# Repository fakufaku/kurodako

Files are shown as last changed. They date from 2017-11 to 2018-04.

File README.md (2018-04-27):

View this project on [CADLAB.io](https://cadlab.io/node/948). 

Kurodako
========

An eight-channel compact microphone array based on the Beaglebone Black and PDM microphones.

Bill of Materials
-----------------

* 8x SPM1437HM4H-B PDM MEMS Microphones (Mouser 721-SPM1437HM4H-B)
* 8x 100nF capacitors, 0805 package
* 2x pin headers 2x40, 2.54mm spaced

Possibly also:
* 4x 100 ohms resistors

If we want to use wires rather than only PCB microphones:
* 8x Micromatch Male-On-Wire 4 pin connector
* 8x Micromatch Female-One-Board 4 pin connector SMD
* flat cable, 1.27mm, 4 wires

Dependencies
------------

* The PRU code doing the low pass filtering [repo](https://github.com/Scrashdown/PRU-Audio-Processing) [Work in progress]

License
-------

2017 (c) Robin Scheibler

This board was designed by Robin Scheibler and is shared under the [Creative Commons CC-BY-SA](https://creativecommons.org/licenses/by-sa/4.0/) license.

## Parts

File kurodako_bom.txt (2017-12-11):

Partlist exported from /Users/scheibler/Documents/eagle/Kurodako/kurodako.sch at 11.12.17 23:04

Part  Value                    Device                   Package                 Description                                        
C1    0.1uF                    CAP0805                  0805                    Capacitor                                          
C2    0.1uF                    CAP0805                  0805                    Capacitor                                          
C3    0.1uF                    CAP0805                  0805                    Capacitor                                          
C4    0.1uF                    CAP0805                  0805                    Capacitor                                          
C5    0.1uF                    CAP0805                  0805                    Capacitor                                          
C6    0.1uF                    CAP0805                  0805                    Capacitor                                          
C7    0.1uF                    CAP0805                  0805                    Capacitor                                          
C8    0.1uF                    CAP0805                  0805                    Capacitor                                          
J1    CONN-4P-MICROMATCH-SMD   CONN-4P-MICROMATCH-SMD   MICROMATCH-4P-SMD                                                          
J2    CONN-4P-MICROMATCH-SMD   CONN-4P-MICROMATCH-SMD   MICROMATCH-4P-SMD                                                          
J3    CONN-4P-MICROMATCH-SMD   CONN-4P-MICROMATCH-SMD   MICROMATCH-4P-SMD                                                          
J4    CONN-4P-MICROMATCH-SMD   CONN-4P-MICROMATCH-SMD   MICROMATCH-4P-SMD                                                          
J5    CONN-4P-MICROMATCH-SMD   CONN-4P-MICROMATCH-SMD   MICROMATCH-4P-SMD                                                          
J6    CONN-4P-MICROMATCH-SMD   CONN-4P-MICROMATCH-SMD   MICROMATCH-4P-SMD                                                          
J7    CONN-4P-MICROMATCH-SMD   CONN-4P-MICROMATCH-SMD   MICROMATCH-4P-SMD                                                          
J8    CONN-4P-MICROMATCH-SMD   CONN-4P-MICROMATCH-SMD   MICROMATCH-4P-SMD                                                          
J9    CONN-4P-MICROMATCH-SMD   CONN-4P-MICROMATCH-SMD   MICROMATCH-4P-SMD                                                          
J10   CONN-4P-MICROMATCH-SMD   CONN-4P-MICROMATCH-SMD   MICROMATCH-4P-SMD                                                          
J11   CONN-4P-MICROMATCH-SMD   CONN-4P-MICROMATCH-SMD   MICROMATCH-4P-SMD                                                          
J12   CONN-4P-MICROMATCH-SMD   CONN-4P-MICROMATCH-SMD   MICROMATCH-4P-SMD                                                          
J13   CONN-4P-MICROMATCH-SMD   CONN-4P-MICROMATCH-SMD   MICROMATCH-4P-SMD                                                          
J14   CONN-4P-MICROMATCH-SMD   CONN-4P-MICROMATCH-SMD   MICROMATCH-4P-SMD                                                          
J15   CONN-4P-MICROMATCH-SMD   CONN-4P-MICROMATCH-SMD   MICROMATCH-4P-SMD                                                          
J16   CONN-4P-MICROMATCH-SMD   CONN-4P-MICROMATCH-SMD   MICROMATCH-4P-SMD                                                          
MIC1L SPM1437HM4H-B            SPM1437HM4H-B            MEMS-MIC-6PAD                                                              
MIC1R SPM1437HM4H-B            SPM1437HM4H-B            MEMS-MIC-6PAD                                                              
MIC2L SPM1437HM4H-B            SPM1437HM4H-B            MEMS-MIC-6PAD                                                              
MIC2R SPM1437HM4H-B            SPM1437HM4H-B            MEMS-MIC-6PAD                                                              
MIC3L SPM1437HM4H-B            SPM1437HM4H-B            MEMS-MIC-6PAD                                                              
MIC3R SPM1437HM4H-B            SPM1437HM4H-B            MEMS-MIC-6PAD                                                              
MIC4L SPM1437HM4H-B            SPM1437HM4H-B            MEMS-MIC-6PAD                                                              
MIC4R SPM1437HM4H-B            SPM1437HM4H-B            MEMS-MIC-6PAD                                                              
R1    DNI                      R-US_R0805               R0805                   RESISTOR, American symbol                          
R2    DNI                      R-US_R0805               R0805                   RESISTOR, American symbol                          
R3    DNI                      R-US_R0805               R0805                   RESISTOR, American symbol                          
R4    DNI                      R-US_R0805               R0805                   RESISTOR, American symbol                          
R5    DNI                      R-US_R0805               R0805                   RESISTOR, American symbol                          
R6    DNI                      R-US_R0805               R0805                   RESISTOR, American symbol                          
R7    DNI                      R-US_R0805               R0805                   RESISTOR, American symbol                          
R8    DNI                      R-US_R0805               R0805                   RESISTOR, American symbol                          
R9    DNI                      R-US_R0805               R0805                   RESISTOR, American symbol                          
R10   100                      R-US_R0805               R0805                   RESISTOR, American symbol                          
R11   100                      R-US_R0805               R0805                   RESISTOR, American symbol                          
R12   100                      R-US_R0805               R0805                   RESISTOR, American symbol                          
R13   100                      R-US_R0805               R0805                   RESISTOR, American symbol                          
P8    2x23 pin header                                                           pin header 100 mil spacing
P9    2x23 pin header                                                           pin header 100 mil spacing

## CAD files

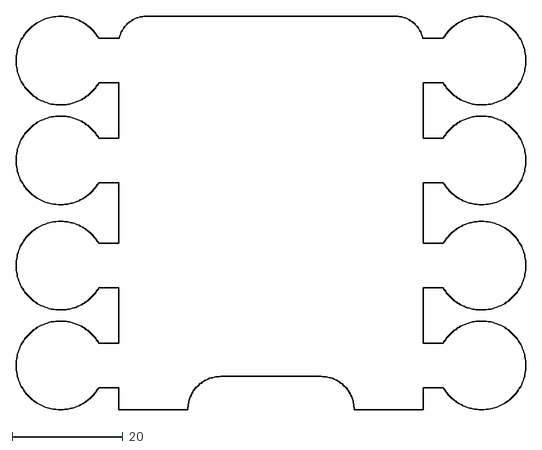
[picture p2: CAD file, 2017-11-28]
pcb_outline/eight_mics_outline.dxf
92.0 x 71.0

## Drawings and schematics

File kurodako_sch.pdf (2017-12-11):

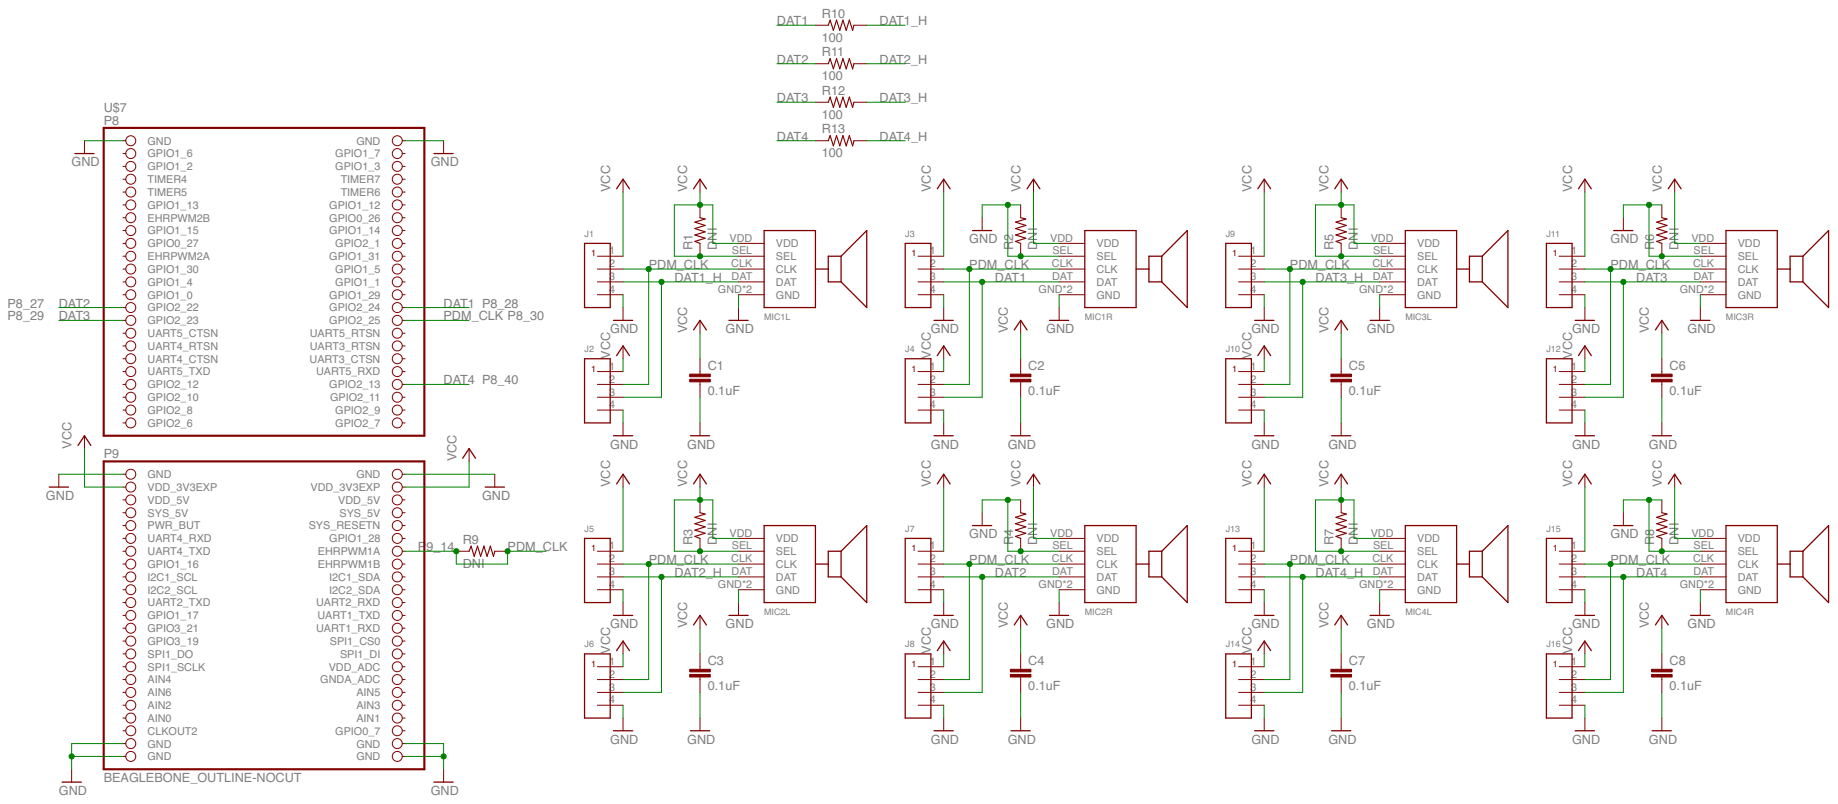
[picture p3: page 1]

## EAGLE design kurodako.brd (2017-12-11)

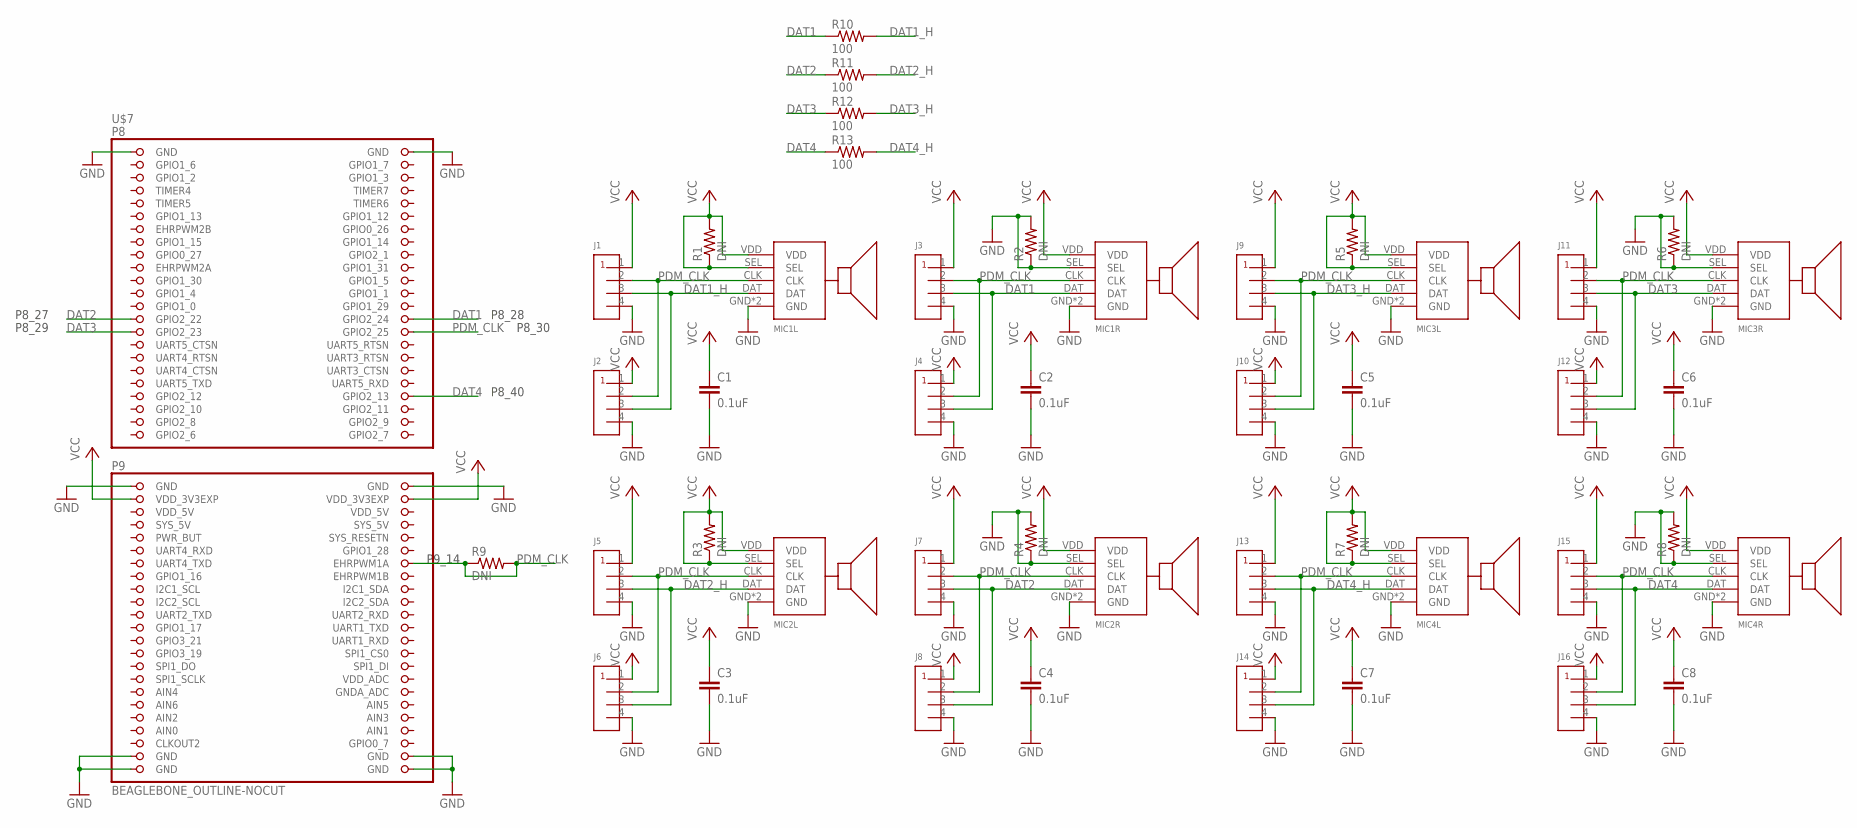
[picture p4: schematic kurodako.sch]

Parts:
C1, C2, C3, C4, C5, C6, C7, C8: 0.1uF; 0805
J1, J2, J3, J4, J5, J6, J7, J8, J9, J10, J11, J12, J13, J14, J15, J16: CONN-4P-MICROMATCH-SMD; MICROMATCH-4P-SMD
MIC1L, MIC1R, MIC2L, MIC2R, MIC3L, MIC3R, MIC4L, MIC4R: SPM1437HM4H-B; MEMS-MIC-6PAD
R1, R2, R3, R4, R5, R6, R7, R8, R9: DNI; R0805
R10, R11, R12, R13: 100; R0805
U$7: BEAGLEBONE_OUTLINE-NOCUT; BEAGLEBONE_SHIELD_NOCUT

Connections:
AIN0: U$7.85 (AIN0)
DAT1: J3.3, J4.3, MIC1R.DAT, R10.1, U$7.28 (GPIO2_24)
DAT1_H: J1.3, J2.3, MIC1L.DAT, R10.2
DAT2: J7.3, J8.3, MIC2R.DAT, R11.1, U$7.27 (GPIO2_22)
DAT2_H: J5.3, J6.3, MIC2L.DAT, R11.2
DAT3: J11.3, J12.3, MIC3R.DAT, R12.1, U$7.29 (GPIO2_23)
DAT3_H: J9.3, J10.3, MIC3L.DAT, R12.2
DAT4: J15.3, J16.3, MIC4R.DAT, R13.1, U$7.40 (GPIO2_13)
DAT4_H: J13.3, J14.3, MIC4L.DAT, R13.2
GND: C1.2, C2.2, C3.2, C4.2, C5.2, C6.2, C7.2, C8.2, J1.4, J2.4, J3.4, J4.4, J5.4, J6.4, J7.4, J8.4, J9.4, J10.4, J11.4, J12.4, J13.4, J14.4, J15.4, J16.4, MIC1L.GND, MIC1L.GND@1 (GND), MIC1R.GND, MIC1R.GND@1 (GND), MIC1R.SEL, MIC2L.GND, MIC2L.GND@1 (GND), MIC2R.GND, MIC2R.GND@1 (GND), MIC2R.SEL, MIC3L.GND, MIC3L.GND@1 (GND), MIC3R.GND, MIC3R.GND@1 (GND), MIC3R.SEL, MIC4L.GND, MIC4L.GND@1 (GND), MIC4R.GND, MIC4R.GND@1 (GND), MIC4R.SEL, R2.1, R2.2, R4.1, R4.2, R6.1, R6.2, R8.1, R8.2, U$7.1 (GND), U$7.2 (GND), U$7.47 (GND), U$7.48 (GND), U$7.89 (GND), U$7.90 (GND), U$7.91 (GND), U$7.92 (GND)
PDM_CLK: J1.2, J2.2, J3.2, J4.2, J5.2, J6.2, J7.2, J8.2, J9.2, J10.2, J11.2, J12.2, J13.2, J14.2, J15.2, J16.2, MIC1L.CLK, MIC1R.CLK, MIC2L.CLK, MIC2R.CLK, MIC3L.CLK, MIC3R.CLK, MIC4L.CLK, MIC4R.CLK, R9.1, R9.2, U$7.30 (GPIO2_25), U$7.60 (EHRPWM1A)
SYS_5V: U$7.53 (SYS_5V)
VCC: C1.1, C2.1, C3.1, C4.1, C5.1, C6.1, C7.1, C8.1, J1.1, J2.1, J3.1, J4.1, J5.1, J6.1, J7.1, J8.1, J9.1, J10.1, J11.1, J12.1, J13.1, J14.1, J15.1, J16.1, MIC1L.SEL, MIC1L.VDD, MIC1R.VDD, MIC2L.SEL, MIC2L.VDD, MIC2R.VDD, MIC3L.SEL, MIC3L.VDD, MIC3R.VDD, MIC4L.SEL, MIC4L.VDD, MIC4R.VDD, R1.1, R1.2, R3.1, R3.2, R5.1, R5.2, R7.1, R7.2, U$7.49 (VDD_3V3EXP), U$7.50 (VDD_3V3EXP)
VDD_5V: U$7.51 (VDD_5V), U$7.52 (VDD_5V)

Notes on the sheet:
P8_40
P8_27
P8_28
P8_29
P8_30
P9_14

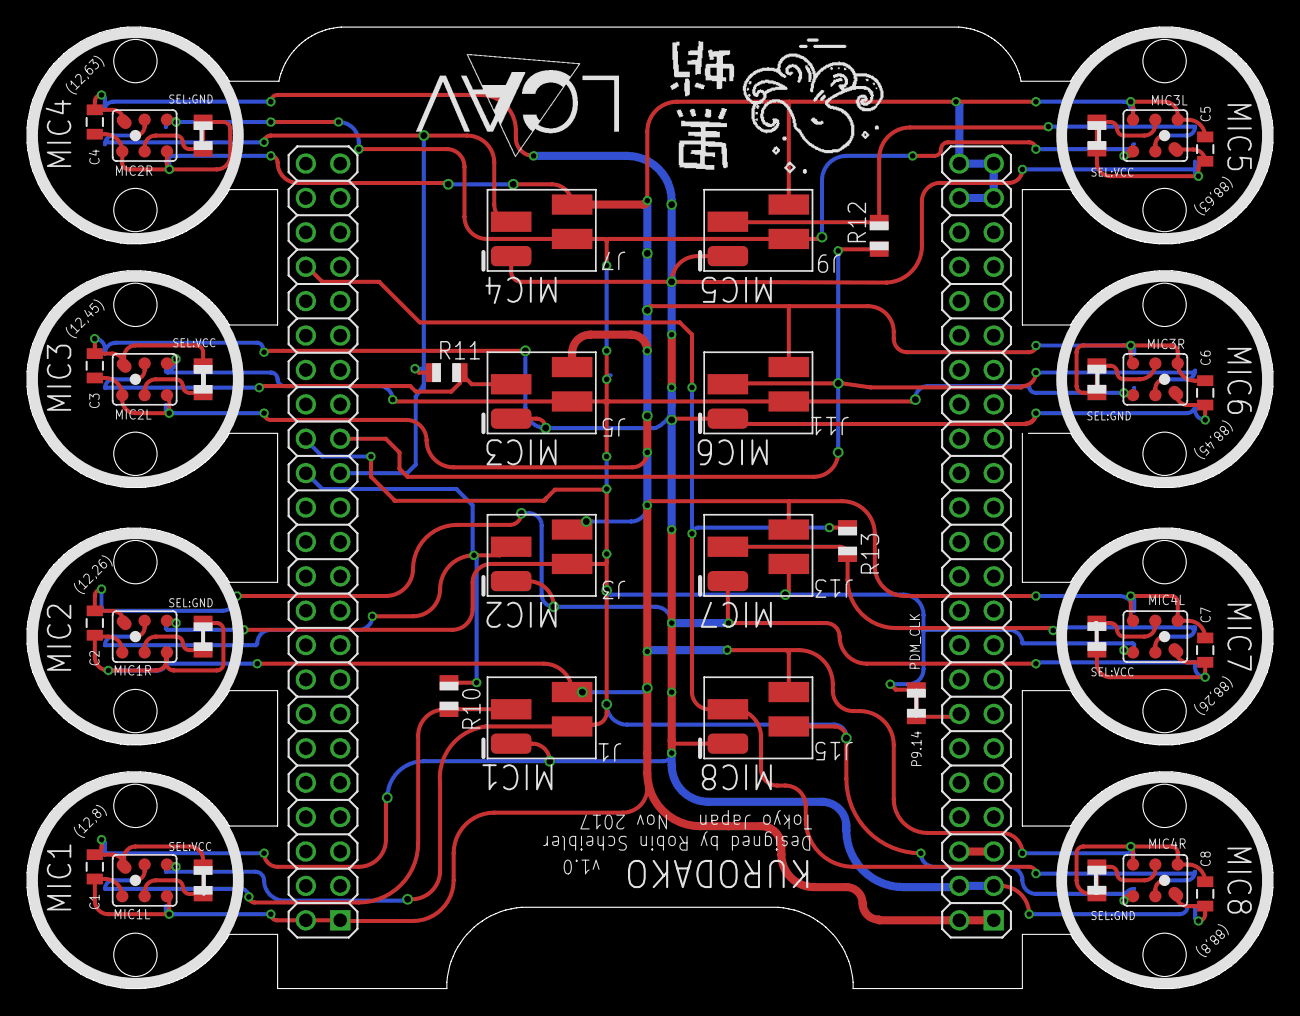
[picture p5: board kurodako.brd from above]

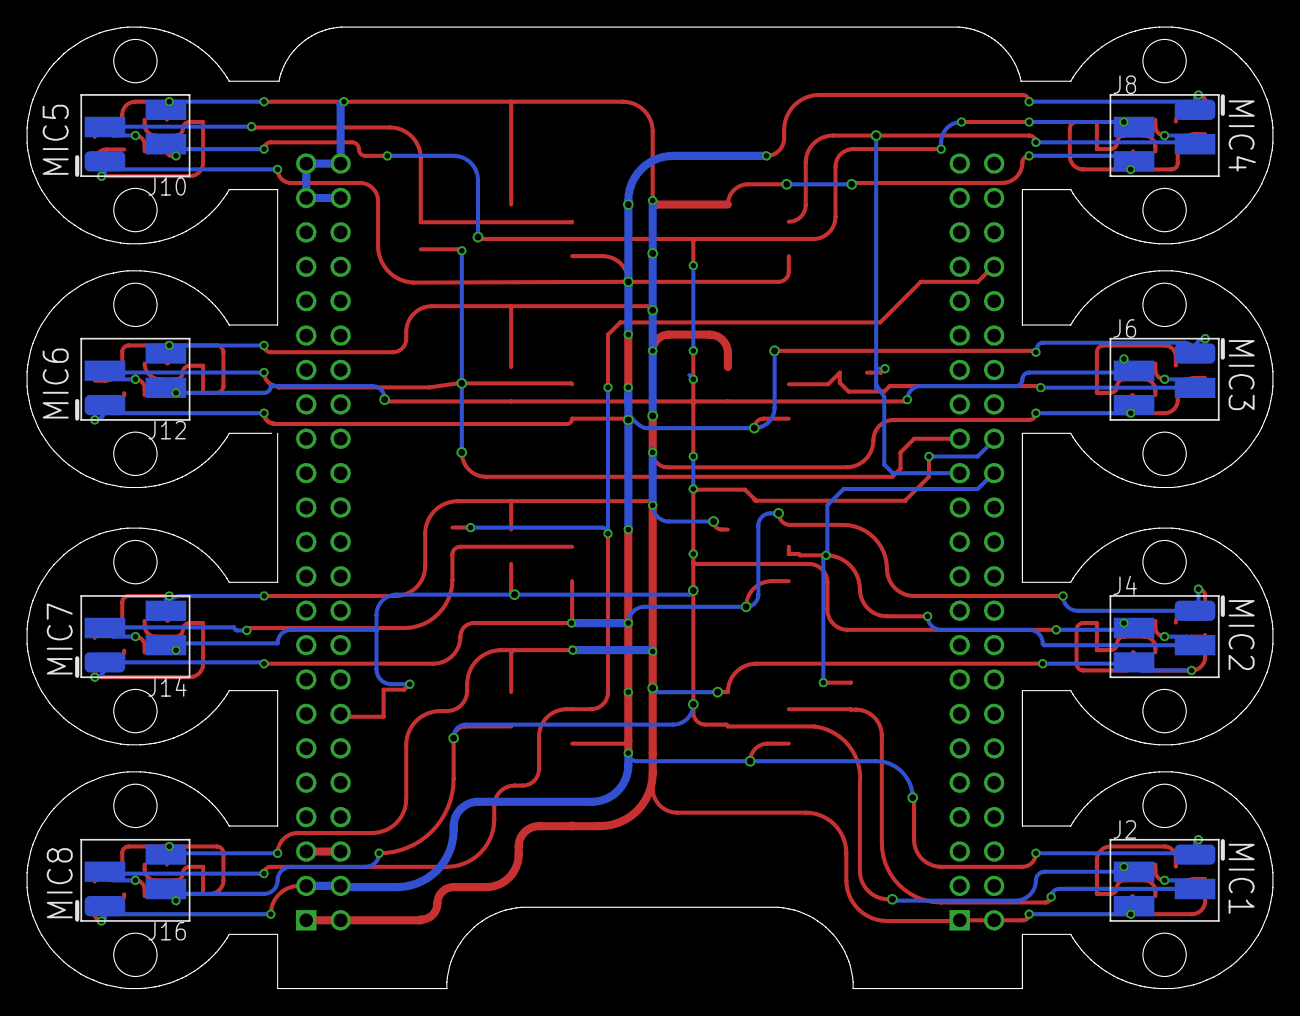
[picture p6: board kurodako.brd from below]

Board: 2 copper layers, 92.0 x 71.0 mm, 47 parts (8 on the bottom side), 12 nets.

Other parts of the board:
U$1: LCAV_LOGO_15MM

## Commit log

2017-11-29 Added resistors on mic high and possiblity to change pdm clk.
    [kurodako.GBL, kurodako.GBO, kurodako.GBP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]
2017-12-11 Added some values for the components on the schematics, a pdf of the schematics and the BOM.
    [kurodako.brd, kurodako.sch]
